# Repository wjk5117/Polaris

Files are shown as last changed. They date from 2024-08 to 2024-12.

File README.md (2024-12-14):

# About
This directory contains all code implementation and hardware designs for Polaris.

# Overview
We present Polaris, the first vision-free fiducial marking system, based on a novel, full-stack magnetic sensing design. 
Polaris can achieve reliable and accurate pose estimation and contextual perception, even in NLOS scenarios. 
Watch our demo video here: [Polaris Demo](https://www.youtube.com/watch?v=gdAEeNdMJk0)

Its core design includes: (1) a novel digital modulation scheme, Magnetic Orientation-shift Keying (MOSK) that can encode key information like waypoints and coordinates with passive magnets; (2) a robust and lightweight magnetic sensing framework to decode and localize the magnetic tags. 
Our design also equips Polaris with three key features: sufficient encoding capacity, robust detection accuracy, and low energy consumption. 
We have built an end-to-end system of Polaris and tested it extensively in real-world scenarios. The testing results have shown Polaris to achieve an accuracy of up to 0.58 mm and 1&deg; in posture estimation with a power consumption of only 25.08 mW.

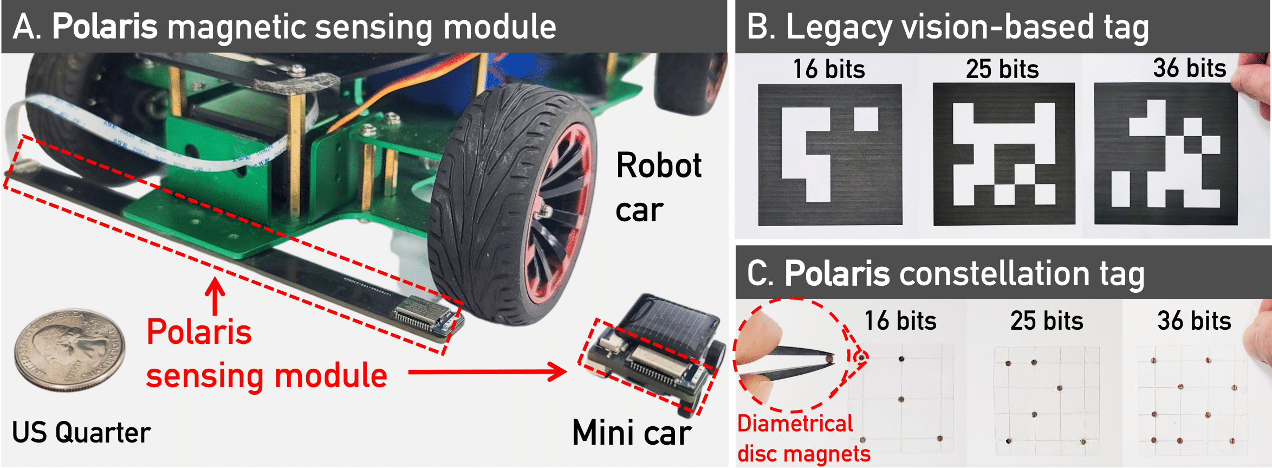
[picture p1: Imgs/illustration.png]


# Setup
To use Polaris, the following steps are required:
* [Building the hardware](#building-the-hardware)
* [Programing the sensor array](#programing-the-sensor-array)
* [Tag fabrication](#tag-fabrication)
* [Running the sensing pipeline](#running-the-sensing-pipeline)

## Building the hardware
We provide the hardware requirements and manufacturing details of Polaris' sensing array in `/PCBs`, please see the related [README](./PCBs/README.md) file.

## Programing the sensor array
We use the Arduino IDE to program the sensor array according to the hardware specifications.
### Arduino IDE setup
1. Download and install the [Arduino IDE](https://www.arduino.cc/en/software). For our prototype, we are using Version 1.8.19.
2. Configure the Arduino IDE for the nRF52 Development Board by following the [official instruction](https://learn.adafruit.com/bluefruit-nrf52-feather-learning-guide/arduino-bsp-setup).
After setup, you can access the board information by clicking on the 'Tools' menu.
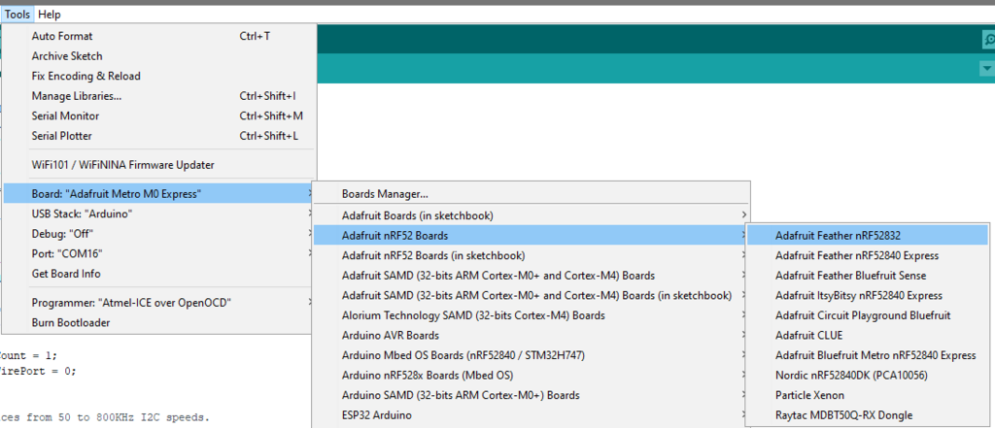
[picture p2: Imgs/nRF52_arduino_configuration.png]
  
3. Install the Adafruit MLX90393 Library for the Arduino IDE:
    - Click 'Sketch' --> 'Include Library' --> 'Manage Libraries...'
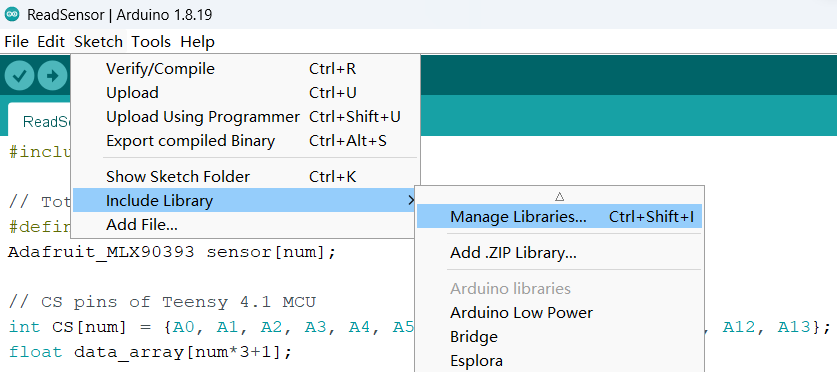
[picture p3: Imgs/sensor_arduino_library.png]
    
    - Search for Adafruit MLX90393, and install the Adafruit MLX90393 library:
    plot

### Programing setup
To program the sensor array using the hardware and Arduino IDE, follow these steps:
1. The microcontroller unit (MCU) in use is the MDBT42Q-512KV2 module, which features a Nordic nRF52832 chip. Since the module is equipped with a blank chip, it needs to be programmed using a J-Link programmer during the initial setup. Please note that this programming step is only required once for a new sensor array.
    - In our prototype, we use a [J-Link EDU Mini](https://www.segger.com/products/debug-probes/j-link/models/j-link-edu-mini/) for programming, one can follow the following hardware setup:
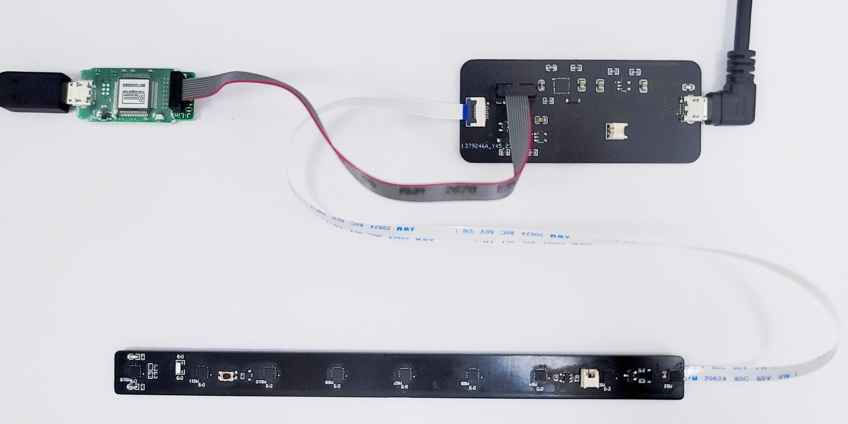
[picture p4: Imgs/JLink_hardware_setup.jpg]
    
    - Open the Arduino IDE --> Click 'Tools' --> Click 'Programmer' --> Choose 'J-Link for Bluefruit nRF52'
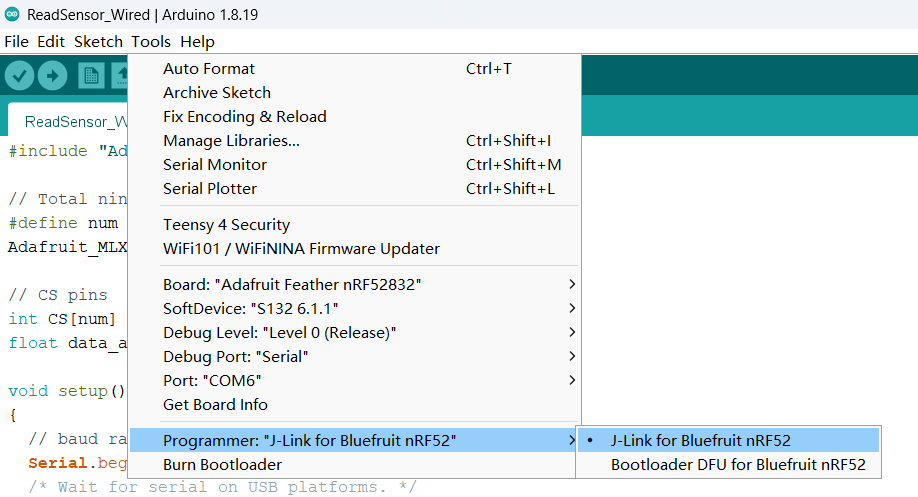
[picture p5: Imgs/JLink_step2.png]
    
    - Click 'Tools' --> Click 'Burn Bootloader'. When you see the following messages, it indicates that the MCU has been programmed successfully.
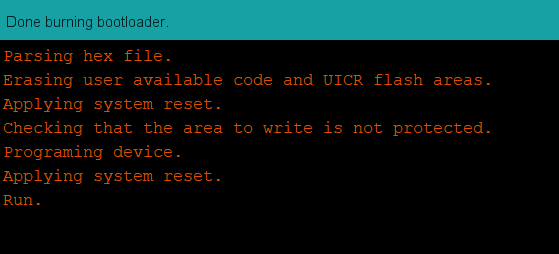
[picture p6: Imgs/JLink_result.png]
    

2. After programming the MCU, you can disconnect the J-Link module and use the Arduino IDE to upload the code that activates the magnetometer readings.
    - Setup the flashing module and the target sensor array and connect to your PC.Make sure the 'Board,' 'Port,' and 'Programmer' settings in the Arduino IDE's 'Tools' menu are properly configured
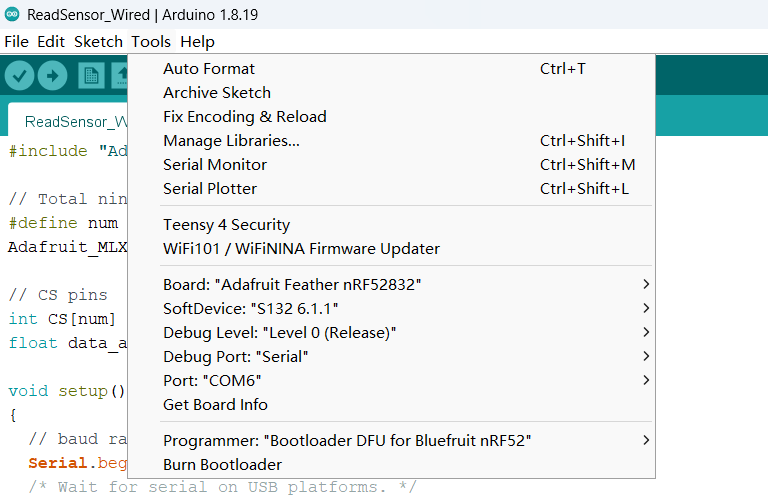
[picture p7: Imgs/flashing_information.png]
    
    - Select the sensing code from the '/Arduino' directory. Both BLE and wired data transmission codes are available for various tasks. Please refer to the relevant file
    - Upload the corresponding Arduino code to the sensor array using the Arduino IDE
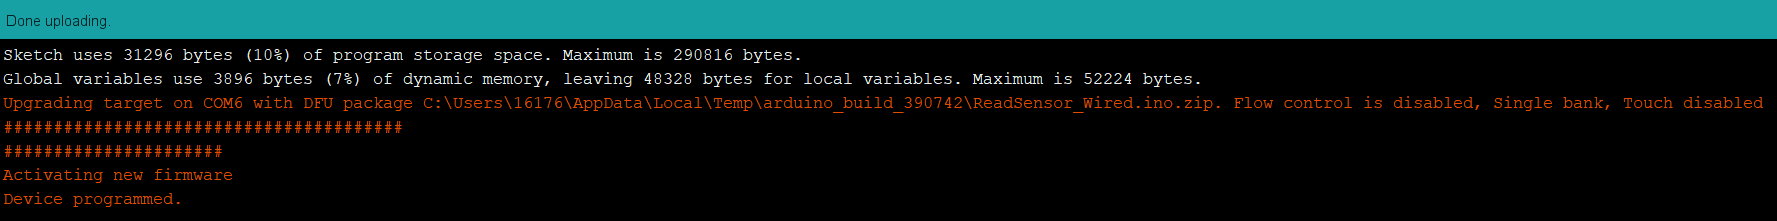
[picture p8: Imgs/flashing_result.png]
    

3. After successfully programming the Arduino code to the sensor array, you can use the Python code in the '/Read_Raw_Sensor' directory to read the raw sensor data.

## Tag fabrication
In our protetype, we use an ultra-thin and durable PVC plane with 
a thickness of 0.2 mm as the substrate and Neodymium (NdFeB) magnets.
To fabricate the tag, we propose a four-step process. 
For more details, please see Sec.7.2 in the paper.
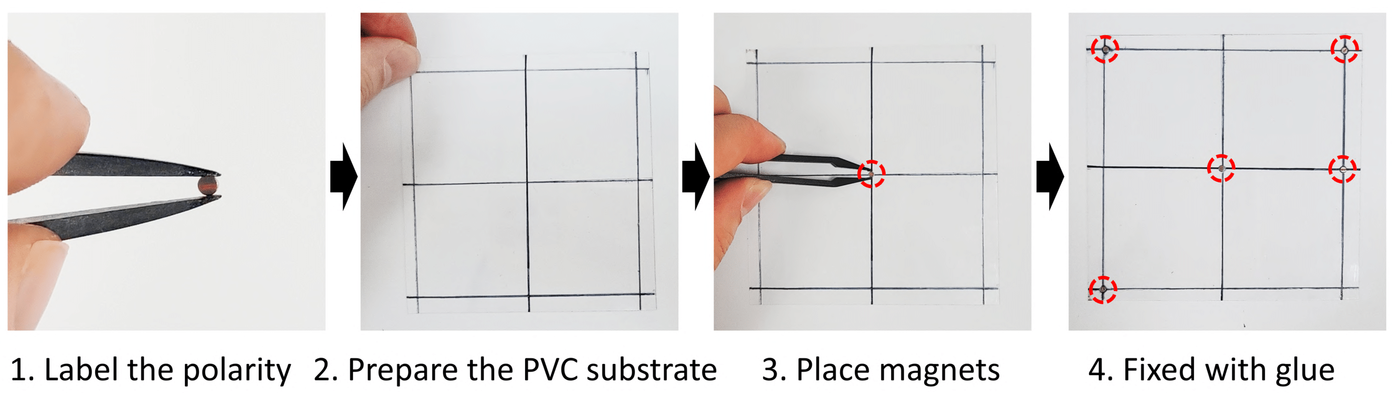
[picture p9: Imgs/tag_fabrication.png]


## Running the sensing pipeline
Once the sensor array is programmed, you can run the Polaris' sensing pipeline. You can find the sensing code in the `/Sensing_Pipeline` directory, please see the related [README](./Sensing_Pipeline/README.md) file.

# Getting started with Polaris
To help users quickly get started with our Polaris system, we’ve provided an offline version of the sensing algorithm framework. 
The relevant data and source code can be found in the the `/Evaluation` directory. 
For more information, please refer to the related [README](./Evaluation/README.md) file.

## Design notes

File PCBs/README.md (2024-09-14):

# Hardware Design of Polaris' Sensor Array

## Description
This directory contains the comprehensive PCB design source codes for Polaris' sensor array, including the sensor bar for fiducial detection and a flashing board for programming the MCU (MDBT42Q-512KV2). 
- The `/SensorArray_RobotCar` directory contains the PCB design for the sensor array used in the robot car.

- The `/SensorArray_MiniCar` directory contains the PCB design for the sensor array used in the mini car.

- The `/Flashing_Module` directory contains the flashing board used to program the MCU for obtaining magnetometer readings.

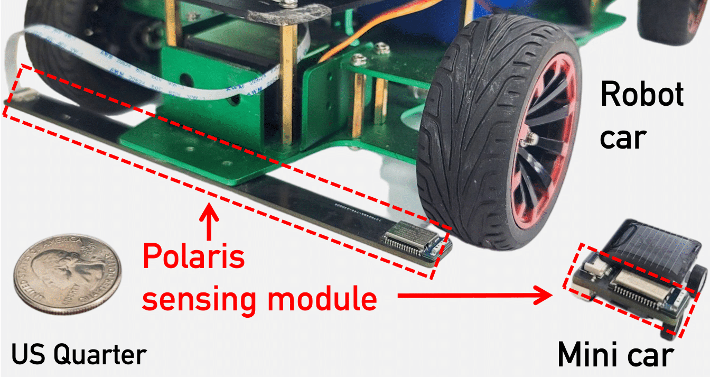
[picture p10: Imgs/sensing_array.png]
plot


## Hardware requirements
The hardware setup requires various components during the design and fabrication process. 
Below is a list of the components used in designing and manufacturing our prototype.

### Sensor array
| Component  | Description | Package | Quantity |
| --- | --- | --- | --- |
|[Raytac MDBT42Q-512KV2](https://www.digikey.com/en/products/detail/raytac/MDBT42Q-512KV2/13677592) | Microcontroller Unit | 41-SMD | 1 |
|[Melexis MLX90393](https://www.digikey.com/en/products/detail/melexis-technologies-nv/MLX90393SLW-ABA-011-RE/5031684) | Magnetometer |16-QFN | M |
|[HCI FC31M2-32.768-NTLNNDTL](https://www.lcsc.com/product-detail/Crystals_HCI-FC31M2-32-768-NTLNNDTL_C5120559.html)  | 32.768kHz Surface Mount Crystal | SMD3215-2P | 1 |
| [Diodes Incorporated AP2112K-3.3TRG1](https://www.lcsc.com/product-detail/Voltage-Regulators-Linear-Low-Drop-Out-LDO-Regulators_Diodes-Incorporated-AP2112K-3-3TRG1_C51118.html)  | Voltage Regulator | SOT-25-5 | 1 |
|[C&K KMR221GLFS](https://www.lcsc.com/product-detail/Tactile-Switches_C-K-KMR221GLFS_C72443.html) | Tactile Switch | SMD | 1 |
| [Vishay Intertech SI2301CDS-T1-GE3](https://www.lcsc.com/product-detail/MOSFETs_Vishay-Intertech-SI2301CDS-T1-GE3_C10487.html) |  P-Channel MOSFET | SOT-23 | 1 |
| [Taiwan Semiconductor 1N4148WS RRG](https://www.lcsc.com/product-detail/Switching-Diodes_Taiwan-Semiconductor-1N4148WS-RRG_C485027.html) | Switching Diodes | SOD-323F | 1 |
| [LRC LMBR120FT1G](https://www.lcsc.com/product-detail/Schottky-Diodes_LRC-LMBR120FT1G_C81143.html) | Schottky Diodes | SOD-123FL | 1 |
| [Resistor](https://www.digikey.com/en/products/filter/chip-resistor-surface-mount/52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) | Chip Resistors | 0402 | 1kΩ (2), 10kΩ (1), 100kΩ (2) |
| [Capacitor](https://www.digikey.com/en/products/filter/ceramic-capacitors/60?s=N4IgTCBcDaIMYEMAOC4EsAuB7ATgAgAYAWAiAXQF8g) | Ceramic Capacitors | 0402| 10uF (3), 1uF (1), 12pF (2), 0.1uF (M) |
| [Inductor](https://www.digikey.com/en/products/filter/fixed-inductors/71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) | Inductors | 0402| 10uH (1), 15nH (1) |
| [Vishay Intertech TLMS1000-GS08](https://www.lcsc.com/product-detail/LED-Indication-Discrete_Vishay-Intertech-TLMS1000-GS08_C241893.html) | LED Indication, Red | 0603 | 1 |
| [Foshan NationStar Optoelectronics NCD0603B1](https://www.lcsc.com/product-detail/LED-Indication-Discrete_Foshan-NationStar-Optoelectronics-NCD0603B1_C84266.html)| LED Indication, Blue  | 0603 | 1 |
| [JUSHUO AFC01-S08FCA-00](https://www.lcsc.com/product-detail/FFC-FPC-Flat-Flexible-Connector-Assemblies_JUSHUO-AFC01-S08FCA-00_C262657.html) |FPC/FFC Connector | SMD, P=0.5mm | 1 |
| [HDGC HDGC1251WR-2P](https://www.lcsc.com/product-detail/Wire-To-Board-Connector_HDGC-HDGC1251WR-2P_C5175203.html) | Wire To Board Connector | Plugin, P=1.25mm | 1 |

### Flashing board
| Component  | Description | Package | Quantity |
| --- | --- | --- | --- |
| [Diodes Incorporated AP2112K-3.3TRG1](https://www.lcsc.com/product-detail/Voltage-Regulators-Linear-Low-Drop-Out-LDO-Regulators_Diodes-Incorporated-AP2112K-3-3TRG1_C51118.html)  | Voltage Regulator | SOT-25-5 | 1 |
| [Vishay Intertech SI2301CDS-T1-GE3](https://www.lcsc.com/product-detail/MOSFETs_Vishay-Intertech-SI2301CDS-T1-GE3_C10487.html) |  P-Channel MOSFET | SOT-23 | 1 |
| [LRC LMBR120FT1G](https://www.lcsc.com/product-detail/Schottky-Diodes_LRC-LMBR120FT1G_C81143.html) | Schottky Diodes | SOD-123FL | 1 |
| [Microchip Tech MCP73831T-2ATI/OT](https://www.lcsc.com/product-detail/Battery-Management_Microchip-Tech-MCP73831T-2ATI-OT_C14879.html) | Battery Management | SOT-23-5 | 1 |
| [SKYWORKS/SILICON LABS CP2104-F03-GM](https://www.lcsc.com/product-detail/USB-Converters_SKYWORKS-SILICON-LABS-CP2104-F03-GM_C430013.html) | USB Converter | QFN-24-EP(4x4)| 1 |
| [TFM-105-12-S-D-A](https://www.digikey.com/en/products/detail/samtec-inc/TFM-105-12-S-D-A/6678838) | Connector Header | SMD 10POS 1.27MM | 1 |
| [Resistor](https://www.digikey.cn/en/products/filter/chip-resistor-surface-mount/52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) | Chip Resistors | 0603 | 1kΩ (3), 100kΩ (3) |
| [Capacitor 0.1uF](https://www.digikey.cn/en/products/filter/ceramic-capacitors/60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) | Ceramic Capacitors | 0603 |  2 |
| [Capacitor 10uF](https://www.digikey.cn/en/products/filter/ceramic-capacitors/60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) | Ceramic Capacitors | 0805 | 5 |
| [PARALIGHT L-C191KRCT](https://www.lcsc.com/product-detail/span-style-background-color-ff0-LED-span-span-style-background-color-ff0-Indication-span-Discrete_PARALIGHT-L-C191KRCT_C2917807.h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) | LED Indication, Orange | 0603 | 1 |
| [SHOU HAN MicroXNJ](https://www.lcsc.com/product-detail/USB-Connectors_SHOU-HAN-MicroXNJ_C404969.html) | Micro-B USB Connectors | SMD | 1 |
| [JUSHUO AFC01-S08FCA-00](https://www.lcsc.com/product-detail/FFC-FPC-Flat-Flexible-Connector-Assemblies_JUSHUO-AFC01-S08FCA-00_C262657.html) |FPC/FFC Connector | SMD, P=0.5mm | 1 |
| [HDGC HDGC1251WR-2P](https://www.lcsc.com/product-detail/Wire-To-Board-Connector_HDGC-HDGC1251WR-2P_C5175203.html) | Wire To Board Connector | Plugin, P=1.25mm | 1 |

## PCB design tool and library
We utilize [EasyEDA](https://easyeda.com/) to design PCB boards.
The component library of capacitive and resistance relies on the standard library.
The footprints for these components can be found in the [EasyEDA 3D model library](https://docs.easyeda.com/en/PCB/3D-Model-Manager/index.html).
The footprint of the MLX90393 magnetometer we used, can see [here](https://www.snapeda.com/parts/MLX90393SLW-ABA-011-RE/Melexis%20Technologies/view-part/551380/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).

After the PCB is manufactured, we also provide an interactive HTML BOM file to facilitate the quick installation of components. 
Please refer to the `BOM.html` file.

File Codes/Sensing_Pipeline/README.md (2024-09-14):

# Sensing Pipeline

## Description
- The `C_Implementation` folder contains a real-time sensing algorithm for detecting Polaris tags implemented in C. 
This code is optimized for low-power devices such as ESP32 chips due to its speed and resource efficiency.

- The `Python_Implementation` folder contains the detection algorithm implemented in Python, which can accelerate algorithm implementation and enhances cross-platform compatibility. It includes:
    - `sensing_real_time.py`: 
    the real-time sensing algorithm for detecting a Polaris tag.
    - `/Utils` folder: 
    contains required utility functions for the sensing pipeline. Specifically, to accelerate the execution of the Python code, we implemented the DDTW algorithm and localization algorithms in C, and embedded them into the Python code as  `.so` (shared object) extension files.
        - `ddtw.c`: C implementation of DDTW algorithm for the polarity orientation.
        - `localize.c`: C implementation of the localization algorithm.
        - `ddtw.so` and `localize.so`: precompiled shared object extension files. 
        To build the `.so` files yourself, use the following command:
            ```
            gcc -shared -o ddtw.so -fPIC ddtw.c -lm 
            ```
    - `template_36_5_80.txt`: 
    this template is generated by synthesizing magnetometer data during the offline stage using Magpylib. 
    It is used to determine the relative orientation of the sensor array with respect to the magnet by DDTW matching process. 
    For more details, please refer to Sec. 6.2.2 of the paper.
    - `requirements.txt`: lists the required Python libraries for the sensing pipeline. 
    You can install each library using the command pip install [library_name]

- The `Simulate_Engine` contains the Python code for generating synthetic magnetic field data templates (e.g., `template_36_5_80.txt`), based on Magpylib. 
The generated templates are used for the magnet polarity orientation matching algorithm. 
For details, please refer to Sec. 6.2.2.

## Note
This directory contains the sensing pipeline for real-time detection, which requires hardwares, e.g., the sensor array and a robot car.
For a quick start with our Polaris system, we’ve provided an offline version of the sensing algorithm framework. 
For more information, please refer to the related [README](../../Evaluation/README.md) file.

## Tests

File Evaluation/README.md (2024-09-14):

# Evaluation-related

## Description
This folder contains all the raw data and code files of the experiments for the artifact submission.

- The `/Data` folder includes all the raw magnetic field readings of three key experiments, saved in CSV format. Each experiment consists of ten sets of data.

- The `/Code` folder contains:
    
    - `sensing_offline.py`: 
    the offline version of the sensing algorithm, which provides quick detection results.
    - `/Utils` folder: 
    contains required utility functions for the sensing pipeline.
    - `template_36_5_80.txt`: 
    this template is generated by synthesizing magnetometer data during the offline stage using Magpylib. 
    It is used to determine the relative orientation of the sensor array with respect to the magnet by DDTW matching process. 
    For more details, please refer to Sec. 6.2.2 of the paper.

- The `/Results` folder contains the processed results for all data, including the estimated heading angle, localization accuracy, tag encoding information, etc.

## How to run
Since the real-time operation of Polaris requires hardware (such as a sensor array), to allow evaluators to quickly get started with our Polaris system, we have provided an offline version of the sensing algorithm framework, `sensing_offline.py`. 
This code reads offline magnetic field data and replicates the results of real-time detection.

To use this code, follow these four simple steps:
- Download our GitHub repository to your local machine.

- Navigate to the `Evaluation/Codes` folder, set up the Python environment, and install the following required libraries:
    - pandas, numpy, datetime, math, ctypes
- Open the `sensing_offline.py` source file, modify `line 598` (the file path to the offline data to be processed) and `line 599` (the file path to save the results) according to your needs. 
    - By default, the code processes the first set of data from the default tag experiment, located at `../Data/Default_Tag/RawData_1.csv`, and saves the results to `../Results/Default_Tag_Exp.txt`.
    ```
    default_tag_file = "../Data/Default_Tag/RawData_1.csv"
    result_txt = "../Results/Default_Tag_Exp.txt"
    ```

- Run the code, and the terminal will display similar information as follows:
    ```
    Begin detecting at 2024-09-10 22:54:56.756350                                           
    Initialize the threshold
    sensor 4: Pre-done with slope threshold equaling to 0.51
    sensor 9: Pre-done with slope threshold equaling to 0.65
    sensor 1: Pre-done with slope threshold equaling to 0.41
    sensor 5: Pre-done with slope threshold equaling to 0.43
    sensor 6: Pre-done with slope threshold equaling to 0.58
    sensor 7: Pre-done with slope threshold equaling to 0.53
    sensor 3: Pre-done with slope threshold equaling to 0.49
    sensor 2: Pre-done with slope threshold equaling to 0.83
    sensor 8: Pre-done with slope threshold equaling to 0.47
    Begin detecting process
    Estimated heading angle: -1.2241516388127511 deg
    The localization error is: 1.4210664527053516 mm
    The decoded bits are: ['111', '111', '111', '111', '111', '111']
    The corresponding tag id is: 262143
    End detection
    ```

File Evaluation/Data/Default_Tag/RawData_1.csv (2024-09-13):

 | Time Stamp | Sensor 1 | Sensor 2 | Sensor 3 | Sensor 4 | Sensor 5 | Sensor 6 | Sensor 7 | Sensor 8 | Sensor 9
0 | 0.0 | (55.95, 9.0, 22.99) | (31.05, -13.5, 63.162) | (23.7, 7.95, 58.564) | (16.8, -5.25, 28.072) | (10.35, -15.3, 42.834) | (2.4, -5.4, 25.41) | (-4.2, -8.85, 43.318) | (9.15, -11.55, 28.556) | (0.6, -19.8, 34.122)
1 | 0.01 | (58.2, 10.65, 24.2) | (34.95, -14.55, 66.55) | (24.0, 6.3, 60.258) | (17.85, -5.25, 28.798) | (9.3, -16.35, 39.688) | (1.2, -6.3, 27.104) | (-2.7, -7.5, 40.898) | (8.25, -9.6, 27.346) | (1.65, -20.25, 32.186)
2 | 0.02 | (55.35, 9.3, 23.716) | (33.75, -14.1, 66.308) | (22.8, 4.95, 59.774) | (16.95, -4.5, 30.25) | (10.65, -14.7, 46.222) | (0.75, -6.0, 25.168) | (-2.1, -6.75, 40.172) | (8.1, -10.8, 29.766) | (1.65, -20.4, 33.638)
3 | 0.03 | (56.25, 9.15, 22.506) | (34.35, -14.1, 66.066) | (23.4, 6.45, 60.258) | (17.1, -6.0, 28.314) | (9.15, -14.55, 41.14) | (2.85, -6.9, 27.104) | (-2.7, -7.35, 41.624) | (7.95, -10.2, 26.378) | (1.2, -21.0, 34.364)
4 | 0.04 | (57.15, 10.05, 23.958) | (37.35, -17.7, 68.97) | (22.8, 6.75, 57.112) | (16.8, -4.65, 28.072) | (9.9, -16.35, 43.56) | (0.0, -6.75, 25.894) | (-1.35, -7.8, 42.834) | (7.35, -10.65, 28.072) | (3.0, -19.5, 35.816)
5 | 0.05 | (56.7, 8.4, 24.2) | (36.9, -12.6, 62.92) | (24.6, 7.2, 60.742) | (16.35, -6.15, 30.734) | (9.6, -16.05, 42.35) | (0.45, -5.25, 26.62) | (-2.1, -9.15, 45.012) | (10.05, -10.05, 29.282) | (2.1, -19.95, 32.912)
6 | 0.060000000000000005 | (55.5, 7.95, 22.99) | (36.0, -12.75, 68.244) | (22.8, 7.05, 59.532) | (18.0, -4.95, 27.104) | (9.3, -14.4, 41.624) | (0.6, -7.05, 26.62) | (-1.95, -9.15, 40.656) | (6.45, -10.8, 28.556) | (2.4, -20.25, 33.154)
7 | 0.07 | (56.55, 9.9, 23.716) | (37.2, -11.1, 65.098) | (24.6, 4.8, 60.984) | (17.25, -6.45, 27.346) | (10.5, -16.05, 43.076) | (2.4, -4.65, 24.926) | (-3.75, -8.1, 42.592) | (8.1, -10.35, 30.008) | (2.85, -19.35, 33.638)
8 | 0.08 | (54.6, 9.0, 24.926) | (34.8, -14.7, 66.308) | (24.15, 6.45, 56.628) | (16.5, -4.5, 27.83) | (10.2, -15.15, 43.318) | (0.15, -5.1, 27.83) | (-2.7, -8.7, 43.802) | (8.4, -10.5, 28.798) | (1.95, -20.25, 32.428)
9 | 0.09 | (56.85, 9.0, 24.442) | (35.25, -11.85, 66.308) | (22.65, 7.8, 59.774) | (17.25, -5.55, 27.588) | (10.35, -15.75, 42.592) | (-0.3, -5.85, 27.104) | (-2.7, -8.7, 42.592) | (7.5, -9.6, 29.766) | (1.5, -21.45, 34.848)
10 | 0.09999999999999999 | (57.75, 8.1, 22.99) | (37.65, -14.7, 65.34) | (24.3, 4.65, 60.016) | (16.8, -6.15, 30.734) | (9.9, -17.55, 43.802) | (1.2, -7.5, 27.346) | (-3.45, -9.0, 41.624) | (9.0, -12.0, 31.218) | (2.7, -20.4, 33.88)
11 | 0.10999999999999999 | (57.15, 9.3, 23.474) | (32.4, -11.25, 64.372) | (22.65, 8.1, 58.322) | (17.55, -5.7, 29.282) | (10.95, -17.55, 41.866) | (2.7, -6.0, 25.41) | (-1.5, -9.3, 42.108) | (8.25, -10.05, 28.556) | (3.0, -19.8, 35.816)
12 | 0.11999999999999998 | (56.1, 8.7, 22.99) | (33.6, -12.9, 65.824) | (22.05, 4.65, 60.742) | (16.8, -5.25, 27.588) | (11.1, -14.4, 41.382) | (0.3, -8.1, 27.83) | (-2.7, -6.75, 41.866) | (8.85, -9.9, 29.04) | (2.55, -19.8, 35.574)
13 | 0.12999999999999998 | (55.95, 10.05, 22.99) | (35.55, -15.3, 61.71) | (22.5, 7.35, 57.354) | (17.1, -5.25, 30.734) | (10.05, -16.8, 42.592) | (2.55, -4.65, 25.652) | (-2.1, -9.0, 41.624) | (9.0, -10.2, 27.83) | (2.55, -22.05, 32.67)
14 | 0.13999999999999999 | (56.85, 9.6, 22.022) | (34.95, -13.65, 66.308) | (23.1, 7.2, 59.048) | (18.0, -4.2, 29.282) | (10.35, -15.9, 41.382) | (2.7, -5.85, 24.684) | (-4.2, -8.55, 41.624) | (7.8, -10.2, 30.25) | (2.7, -19.8, 33.396)
15 | 0.15 | (55.95, 8.25, 22.99) | (36.15, -12.3, 65.098) | (22.35, 4.95, 57.596) | (17.1, -6.9, 28.314) | (8.55, -16.8, 40.898) | (0.75, -7.8, 26.62) | (-3.6, -9.45, 41.14) | (9.75, -11.4, 28.556) | (1.5, -20.85, 33.638)
16 | 0.16 | (55.8, 9.45, 23.232) | (32.4, -12.45, 64.856) | (22.5, 4.05, 58.806) | (17.25, -5.7, 29.282) | (10.05, -15.3, 41.14) | (1.95, -7.05, 25.652) | (-3.45, -6.45, 39.93) | (9.3, -11.55, 28.798) | (3.0, -20.55, 35.816)
17 | 0.17 | (57.6, 9.6, 23.232) | (36.15, -13.2, 66.308) | (24.3, 5.7, 58.08) | (16.5, -5.1, 29.282) | (10.95, -17.25, 40.898) | (2.55, -6.75, 26.136) | (-2.4, -9.75, 42.108) | (9.75, -11.55, 27.588) | (3.0, -19.2, 34.122)
18 | 0.18000000000000002 | (55.8, 9.45, 23.716) | (35.55, -14.7, 68.97) | (21.45, 4.2, 60.984) | (16.5, -5.25, 28.072) | (9.6, -14.55, 41.382) | (2.85, -7.35, 25.652) | (-1.2, -8.85, 41.624) | (8.1, -9.6, 29.766) | (1.8, -18.9, 33.396)
19 | 0.19000000000000003 | (55.65, 9.75, 23.716) | (35.85, -13.65, 69.212) | (22.35, 4.8, 58.322) | (17.7, -4.5, 29.524) | (10.35, -16.5, 42.108) | (2.55, -6.3, 25.652) | (-2.7, -10.05, 41.624) | (7.5, -9.9, 30.008) | (1.95, -21.3, 35.816)
20 | 0.20000000000000004 | (56.1, 8.55, 23.232) | (33.9, -13.35, 64.13) | (23.55, 5.7, 57.596) | (16.8, -4.5, 29.524) | (9.15, -16.35, 42.834) | (0.45, -7.5, 26.862) | (-2.7, -8.55, 40.656) | (8.55, -11.1, 27.588) | (1.35, -21.15, 33.154)
21 | 0.21000000000000005 | (55.5, 8.4, 23.232) | (35.85, -12.6, 65.824) | (22.5, 5.4, 60.258) | (15.9, -5.7, 29.282) | (8.85, -17.25, 41.624) | (0.6, -6.45, 27.588) | (-2.1, -9.3, 41.866) | (8.7, -10.2, 28.072) | (2.1, -21.9, 34.122)
22 | 0.22000000000000006 | (55.8, 7.8, 23.958) | (38.1, -16.65, 68.002) | (25.05, 5.25, 54.208) | (16.65, -4.2, 30.25) | (9.0, -16.2, 41.14) | (0.3, -7.95, 26.62) | (-1.8, -7.95, 43.076) | (8.85, -11.4, 29.04) | (1.65, -20.7, 36.058)
23 | 0.23000000000000007 | (56.4, 10.05, 23.716) | (34.5, -13.95, 65.824) | (25.65, 5.85, 57.112) | (17.55, -7.5, 30.734) | (9.6, -17.7, 42.108) | (1.5, -6.3, 24.442) | (-2.85, -8.85, 40.414) | (8.25, -9.45, 27.346) | (3.15, -21.3, 32.428)
24 | 0.24000000000000007 | (58.05, 10.35, 22.506) | (34.05, -11.1, 68.486) | (21.6, 3.3, 57.596) | (15.75, -6.0, 28.072) | (11.7, -16.65, 41.14) | (1.8, -7.65, 25.652) | (-0.75, -7.95, 42.108) | (8.1, -9.6, 31.218) | (1.8, -21.45, 33.88)
25 | 0.25000000000000006 | (56.1, 8.7, 23.474) | (37.35, -15.6, 68.244) | (22.95, 4.5, 59.532) | (17.55, -4.95, 30.25) | (10.65, -16.65, 42.35) | (1.5, -5.25, 27.588) | (-1.65, -8.25, 40.898) | (8.25, -10.05, 29.766) | (2.25, -20.4, 34.848)
26 | 0.26000000000000006 | (57.6, 7.5, 24.442) | (35.4, -15.9, 66.308) | (22.95, 5.25, 57.596) | (17.25, -5.85, 27.83) | (11.25, -16.65, 42.108) | (2.1, -6.0, 26.62) | (-4.2, -7.5, 43.802) | (7.8, -11.55, 30.492) | (2.4, -21.15, 30.008)
27 | 0.2700000000000001 | (55.5, 9.3, 24.442) | (35.55, -14.55, 66.066) | (23.1, 5.7, 55.418) | (17.1, -5.25, 30.008) | (8.85, -17.4, 41.14) | (0.9, -7.65, 25.168) | (-4.5, -9.6, 41.624) | (10.35, -10.8, 25.41) | (2.25, -19.2, 34.364)
28 | 0.2800000000000001 | (56.25, 7.65, 23.474) | (37.8, -16.05, 63.888) | (24.3, 4.05, 57.596) | (16.65, -3.9, 28.072) | (9.15, -16.8, 44.77) | (1.95, -5.7, 26.862) | (-1.8, -8.25, 41.624) | (8.55, -12.0, 27.104) | (1.35, -22.2, 34.606)
29 | 0.2900000000000001 | (57.6, 9.15, 24.684) | (34.95, -12.45, 68.97) | (24.6, 7.8, 56.628) | (16.05, -5.1, 28.556) | (10.2, -17.4, 41.382) | (0.6, -6.75, 24.926) | (-3.45, -7.65, 42.592) | (8.85, -11.25, 30.25) | (2.25, -20.4, 34.848)
30 | 0.3000000000000001 | (56.85, 9.6, 23.716) | (35.4, -12.9, 65.582) | (24.6, 4.05, 57.838) | (17.1, -4.35, 29.282) | (11.25, -16.2, 42.35) | (2.4, -7.5, 29.282) | (-2.85, -9.3, 43.56) | (8.85, -10.35, 28.798) | (1.2, -22.05, 35.816)
31 | 0.3100000000000001 | (57.45, 9.45, 22.99) | (34.8, -14.4, 64.372) | (23.7, 5.55, 59.29) | (17.7, -5.55, 30.008) | (8.7, -16.95, 42.834) | (2.7, -7.35, 29.766) | (-4.35, -10.05, 43.076) | (8.85, -10.2, 27.104) | (3.0, -21.6, 33.638)
32 | 0.3200000000000001 | (56.1, 9.15, 24.442) | (35.55, -12.75, 64.372) | (22.2, 6.75, 56.87) | (18.3, -4.65, 27.104) | (9.3, -16.95, 44.286) | (3.45, -6.45, 26.136) | (-4.05, -8.1, 40.898) | (9.6, -9.45, 28.556) | (1.65, -21.0, 32.67)
33 | 0.3300000000000001 | (57.15, 9.45, 23.474) | (34.8, -14.25, 64.372) | (25.2, 5.85, 55.902) | (17.85, -5.85, 28.072) | (11.55, -15.75, 39.93) | (1.5, -7.05, 24.684) | (-3.0, -9.3, 39.688) | (9.0, -10.5, 29.282) | (3.0, -20.25, 32.912)
34 | 0.34000000000000014 | (55.65, 7.8, 23.474) | (34.2, -13.05, 67.034) | (21.15, 2.55, 60.5) | (14.55, -4.95, 28.314) | (9.15, -17.1, 41.14) | (1.65, -6.75, 26.62) | (-3.0, -8.25, 41.14) | (7.8, -10.35, 27.104) | (2.1, -20.7, 33.396)
35 | 0.35000000000000014 | (56.85, 8.4, 22.748) | (34.35, -13.5, 65.582) | (23.7, 2.85, 56.386) | (16.8, -6.15, 28.314) | (10.05, -15.45, 41.14) | (1.35, -6.15, 25.41) | (-2.85, -8.55, 42.35) | (8.7, -10.65, 28.314) | (3.9, -20.25, 33.88)
36 | 0.36000000000000015 | (56.25, 7.8, 23.474) | (35.25, -15.3, 66.308) | (22.35, 4.05, 56.144) | (16.65, -5.85, 30.976) | (10.2, -15.9, 42.35) | (2.25, -7.8, 26.62) | (-2.55, -8.1, 39.688) | (8.1, -9.9, 26.862) | (2.85, -21.15, 31.218)
37 | 0.37000000000000016 | (56.55, 8.85, 23.232) | (37.2, -16.05, 68.486) | (23.7, 4.65, 59.048) | (17.55, -6.15, 27.83) | (10.5, -15.75, 39.93) | (2.7, -8.4, 27.346) | (-3.15, -9.3, 41.624) | (9.6, -9.15, 30.25) | (2.25, -20.7, 33.638)
38 | 0.38000000000000017 | (55.95, 9.6, 22.99) | (35.85, -12.75, 67.276) | (21.15, 7.8, 59.774) | (16.65, -5.85, 28.556) | (11.1, -16.5, 42.592) | (3.6, -6.15, 23.716) | (-3.15, -8.7, 42.35) | (7.95, -10.5, 31.46) | (1.65, -20.25, 34.848)
39 | 0.3900000000000002 | (58.2, 8.55, 22.506) | (33.75, -12.75, 63.162) | (21.9, 4.95, 58.08) | (17.85, -3.45, 28.314) | (10.5, -15.45, 40.898) | (0.9, -5.85, 26.136) | (-3.6, -8.4, 43.076) | (8.55, -9.3, 27.588) | (3.75, -20.1, 34.122)
40 | 0.4000000000000002 | (55.65, 11.1, 22.748) | (38.25, -15.45, 66.308) | (23.85, 5.7, 60.742) | (17.1, -5.55, 28.556) | (9.0, -15.75, 41.382) | (2.4, -7.8, 25.652) | (-3.9, -9.0, 40.656) | (9.0, -10.5, 29.282) | (2.55, -19.8, 33.88)
41 | 0.4100000000000002 | (57.6, 9.0, 22.99) | (35.85, -13.8, 68.486) | (23.7, 6.3, 55.902) | (15.75, -3.3, 25.894) | (9.45, -15.6, 41.14) | (1.65, -7.05, 29.524) | (-2.1, -9.75, 43.076) | (7.8, -10.65, 26.62) | (1.5, -20.85, 37.994)
42 | 0.4200000000000002 | (57.0, 9.45, 23.474) | (36.9, -14.25, 66.308) | (20.1, 5.4, 54.692) | (17.7, -6.15, 29.282) | (10.2, -15.9, 40.898) | (1.8, -6.9, 25.894) | (-1.65, -8.85, 41.382) | (8.1, -10.65, 29.524) | (2.1, -19.95, 35.816)
43 | 0.4300000000000002 | (55.65, 9.6, 23.474) | (36.3, -15.15, 67.034) | (22.65, 5.4, 57.838) | (15.9, -6.0, 29.282) | (10.05, -16.8, 42.834) | (3.3, -6.75, 27.83) | (-2.85, -7.05, 42.108) | (9.6, -10.95, 30.25) | (3.75, -22.05, 34.848)
44 | 0.4400000000000002 | (57.45, 9.15, 22.99) | (36.6, -14.4, 68.728) | (22.65, 4.5, 57.354) | (16.5, -5.1, 29.282) | (10.5, -15.15, 43.318) | (2.4, -6.0, 28.556) | (-4.5, -10.5, 41.624) | (8.85, -9.6, 28.798) | (1.2, -19.8, 31.218)
45 | 0.45000000000000023 | (56.4, 10.65, 22.99) | (34.35, -12.15, 68.002) | (23.85, 2.85, 57.596) | (17.55, -5.25, 29.282) | (9.45, -16.65, 42.35) | (0.75, -6.0, 28.314) | (-2.7, -8.4, 41.866) | (6.9, -10.95, 30.976) | (1.65, -20.4, 32.428)
46 | 0.46000000000000024 | (56.55, 10.35, 21.78) | (37.5, -14.1, 66.55) | (22.05, 3.6, 54.692) | (16.8, -5.25, 28.556) | (10.5, -15.75, 41.624) | (2.55, -5.7, 28.556) | (-3.45, -7.95, 42.108) | (8.4, -9.75, 30.976) | (1.5, -21.3, 34.606)
47 | 0.47000000000000025 | (55.05, 6.9, 22.264) | (33.3, -13.2, 67.276) | (22.5, 4.2, 58.806) | (15.6, -4.5, 27.346) | (10.05, -15.15, 39.204) | (2.55, -6.6, 23.958) | (-2.4, -8.7, 40.898) | (10.35, -10.8, 28.314) | (2.55, -21.9, 33.88)
48 | 0.48000000000000026 | (59.1, 9.3, 23.474) | (36.9, -14.1, 65.824) | (21.0, 5.85, 57.354) | (18.0, -5.1, 27.346) | (11.1, -15.3, 43.318) | (1.8, -6.45, 26.136) | (-4.35, -8.7, 41.14) | (8.1, -10.2, 29.282) | (4.05, -20.25, 33.88)
49 | 0.49000000000000027 | (56.4, 9.6, 23.474) | (34.35, -16.05, 64.614) | (22.35, 4.2, 55.902) | (17.85, -4.2, 29.766) | (10.8, -16.35, 42.834) | (1.35, -6.3, 24.926) | (-3.6, -9.45, 40.656) | (7.35, -10.35, 29.04) | (2.25, -19.8, 33.88)
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

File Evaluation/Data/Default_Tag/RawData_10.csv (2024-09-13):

 | Time Stamp | Sensor 1 | Sensor 2 | Sensor 3 | Sensor 4 | Sensor 5 | Sensor 6 | Sensor 7 | Sensor 8 | Sensor 9
0 | 0.0 | (54.75, 15.15, 47.19) | (36.45, -14.4, 65.824) | (22.95, 6.0, 55.66) | (16.95, -4.8, 27.346) | (9.15, -16.35, 42.35) | (0.9, -6.45, 27.588) | (-1.35, -8.85, 39.93) | (8.25, -9.75, 28.798) | (2.85, -19.2, 35.574)
1 | 0.01 | (58.05, 9.3, 48.884) | (34.5, -13.65, 64.13) | (23.85, 3.15, 60.742) | (18.0, -4.2, 28.072) | (9.45, -15.6, 41.866) | (2.55, -5.1, 25.894) | (-2.4, -9.3, 41.14) | (8.4, -6.9, 28.798) | (2.25, -18.9, 36.3)
2 | 0.02 | (58.5, 9.9, 47.674) | (33.9, -12.3, 61.71) | (22.2, 3.75, 55.902) | (16.5, -6.75, 28.556) | (9.75, -15.6, 41.866) | (1.95, -5.85, 26.862) | (-2.7, -9.45, 41.14) | (8.55, -7.8, 29.766) | (1.2, -17.55, 35.332)
3 | 0.03 | (57.6, 8.7, 50.82) | (34.8, -13.2, 64.614) | (22.65, 1.65, 56.87) | (15.9, -5.85, 29.282) | (10.95, -16.2, 41.14) | (4.35, -8.7, 26.862) | (-2.1, -9.0, 39.688) | (8.25, -7.35, 28.798) | (4.05, -18.6, 35.816)
4 | 0.04 | (56.4, 10.65, 45.738) | (35.1, -12.15, 64.856) | (22.35, 4.35, 54.934) | (17.1, -6.6, 30.734) | (11.4, -16.95, 43.802) | (3.75, -8.85, 26.62) | (-2.85, -9.6, 41.866) | (10.05, -8.55, 28.798) | (1.35, -19.5, 36.3)
5 | 0.05 | (55.65, 7.8, 48.642) | (37.8, -13.95, 63.404) | (22.35, 4.2, 57.354) | (18.15, -6.3, 27.104) | (10.8, -16.35, 42.35) | (5.85, -9.6, 25.894) | (-0.6, -7.35, 42.592) | (8.7, -8.1, 28.798) | (2.55, -18.0, 33.396)
6 | 0.060000000000000005 | (56.7, 9.15, 46.222) | (34.2, -12.75, 65.582) | (23.1, 5.1, 55.418) | (18.45, -5.85, 27.104) | (9.75, -15.9, 44.77) | (4.8, -7.95, 27.588) | (-2.4, -7.2, 40.898) | (9.6, -8.7, 28.556) | (1.95, -18.3, 34.364)
7 | 0.07 | (56.1, 8.55, 44.286) | (35.1, -14.25, 63.646) | (22.05, 4.8, 56.386) | (16.2, -4.5, 27.346) | (10.8, -15.15, 43.318) | (4.5, -5.4, 25.168) | (-3.15, -9.15, 41.14) | (7.2, -7.8, 28.798) | (2.1, -18.3, 34.364)
8 | 0.08 | (56.25, 9.75, 44.528) | (34.95, -13.8, 65.098) | (22.95, 1.35, 58.806) | (18.0, -5.55, 27.83) | (12.45, -13.8, 42.108) | (3.15, -4.35, 26.378) | (-1.65, -7.8, 41.382) | (9.9, -8.85, 30.492) | (4.95, -18.15, 32.428)
9 | 0.09 | (58.95, 8.55, 42.35) | (35.85, -13.95, 64.13) | (23.25, 6.0, 56.144) | (16.8, -3.45, 30.008) | (11.55, -14.4, 42.108) | (1.35, -4.5, 27.588) | (-3.45, -6.45, 40.898) | (7.8, -8.25, 28.798) | (1.8, -17.85, 32.67)
10 | 0.09999999999999999 | (60.45, 10.2, 50.82) | (34.65, -12.0, 62.92) | (21.3, 5.55, 53.966) | (16.35, -5.7, 29.524) | (10.8, -15.15, 44.044) | (1.65, -3.75, 27.346) | (-2.55, -6.3, 41.624) | (9.45, -8.1, 29.524) | (0.75, -19.8, 36.3)
11 | 0.10999999999999999 | (58.95, 11.55, 50.82) | (35.25, -14.55, 66.55) | (24.15, 3.6, 57.354) | (16.95, -5.1, 29.524) | (9.3, -14.55, 41.14) | (2.25, -4.8, 29.04) | (-2.1, -7.05, 42.592) | (10.5, -8.85, 29.524) | (2.55, -19.65, 33.638)
12 | 0.11999999999999998 | (59.1, 8.55, 45.254) | (34.35, -11.55, 64.372) | (23.55, 4.2, 55.418) | (17.7, -6.0, 27.83) | (9.3, -15.45, 43.318) | (2.25, -6.0, 26.862) | (-1.35, -7.65, 42.108) | (7.95, -9.0, 31.46) | (2.25, -17.85, 34.848)
13 | 0.12999999999999998 | (56.25, 10.2, 48.158) | (34.35, -14.4, 64.614) | (22.95, 3.9, 57.838) | (16.95, -6.3, 26.62) | (9.45, -16.35, 43.076) | (3.15, -7.05, 28.798) | (-2.55, -7.05, 39.688) | (7.35, -9.6, 30.008) | (2.25, -18.9, 34.606)
14 | 0.13999999999999999 | (57.3, 7.5, 46.706) | (34.05, -14.7, 64.13) | (21.75, 4.65, 52.272) | (15.9, -4.95, 28.314) | (10.95, -16.35, 44.77) | (1.95, -5.1, 26.136) | (-2.85, -7.35, 38.478) | (6.75, -7.8, 29.524) | (2.25, -19.05, 37.026)
15 | 0.15 | (57.75, 12.0, 44.77) | (35.1, -14.25, 63.162) | (21.75, 5.4, 57.112) | (17.7, -3.45, 27.104) | (9.3, -14.4, 41.14) | (1.95, -4.8, 27.346) | (-2.25, -6.45, 43.802) | (8.55, -8.25, 30.976) | (2.4, -17.55, 34.364)
16 | 0.16 | (55.8, 10.65, 45.496) | (34.65, -14.7, 66.066) | (22.35, 3.9, 55.418) | (16.35, -4.95, 26.378) | (10.5, -12.75, 42.834) | (0.3, -6.0, 29.282) | (-2.4, -8.25, 43.076) | (7.65, -8.7, 29.524) | (1.65, -18.9, 35.816)
17 | 0.17 | (57.6, 12.9, 51.546) | (34.8, -10.8, 65.824) | (21.75, 6.75, 57.112) | (16.05, -5.1, 29.524) | (11.1, -15.3, 42.834) | (4.05, -4.5, 25.894) | (-1.8, -6.9, 42.834) | (8.55, -8.1, 30.25) | (2.4, -18.45, 34.364)
18 | 0.18000000000000002 | (56.25, 10.2, 45.012) | (36.3, -14.85, 63.888) | (21.0, 5.1, 54.692) | (17.85, -5.4, 28.072) | (10.8, -14.25, 41.14) | (3.75, -6.75, 28.314) | (-2.7, -7.05, 43.318) | (7.95, -7.05, 31.702) | (4.05, -18.3, 34.606)
19 | 0.19000000000000003 | (53.7, 9.3, 45.98) | (36.0, -12.75, 64.614) | (23.55, 2.55, 54.208) | (16.35, -5.1, 24.684) | (10.35, -16.05, 41.624) | (1.65, -4.65, 27.588) | (-1.35, -7.65, 40.414) | (9.9, -9.0, 30.008) | (3.6, -18.15, 34.606)
20 | 0.20000000000000004 | (55.65, 10.35, 41.866) | (36.15, -15.75, 64.372) | (21.9, 5.4, 55.66) | (15.9, -6.3, 25.652) | (9.9, -15.15, 41.382) | (1.8, -7.2, 27.588) | (-2.85, -8.25, 41.866) | (8.25, -7.2, 32.428) | (3.6, -19.8, 34.364)
21 | 0.21000000000000005 | (58.35, 10.95, 48.158) | (34.95, -14.7, 67.034) | (24.3, 2.7, 58.806) | (17.55, -5.7, 28.314) | (10.2, -16.35, 41.624) | (3.9, -5.85, 27.346) | (-3.45, -9.45, 41.382) | (10.35, -9.6, 29.766) | (2.4, -18.45, 35.816)
22 | 0.22000000000000006 | (59.25, 6.45, 50.82) | (36.75, -13.8, 66.792) | (24.6, 3.0, 54.934) | (16.2, -6.0, 26.136) | (8.7, -16.65, 41.624) | (1.95, -5.55, 26.862) | (-1.8, -8.25, 43.076) | (9.0, -8.55, 31.702) | (2.4, -19.5, 33.638)
23 | 0.23000000000000007 | (56.7, 8.25, 47.432) | (32.7, -12.75, 64.614) | (23.55, 2.55, 54.934) | (17.55, -6.15, 27.83) | (10.8, -16.05, 40.172) | (3.3, -6.3, 24.684) | (-2.25, -6.6, 41.14) | (9.0, -8.4, 29.04) | (2.25, -19.65, 35.09)
24 | 0.24000000000000007 | (56.55, 7.8, 46.706) | (36.45, -14.25, 64.13) | (23.1, 4.8, 55.902) | (16.8, -6.9, 26.62) | (9.3, -15.9, 41.866) | (1.05, -5.85, 25.41) | (-1.65, -8.55, 41.382) | (8.7, -7.2, 30.008) | (2.7, -19.8, 33.154)
25 | 0.25000000000000006 | (56.7, 11.25, 52.03) | (35.25, -12.3, 61.226) | (21.75, 3.15, 57.596) | (16.95, -6.9, 25.168) | (10.8, -17.1, 43.56) | (2.1, -5.25, 28.072) | (-1.65, -8.4, 40.656) | (9.9, -7.2, 28.798) | (3.15, -19.2, 34.364)
26 | 0.26000000000000006 | (58.8, 9.45, 47.432) | (36.9, -13.05, 64.372) | (23.55, 2.7, 55.902) | (15.45, -4.95, 27.588) | (10.95, -16.5, 43.56) | (2.4, -6.3, 26.136) | (-2.1, -7.65, 40.172) | (7.95, -8.1, 29.524) | (1.8, -19.65, 31.218)
27 | 0.2700000000000001 | (59.85, 7.8, 47.19) | (34.35, -13.65, 60.5) | (25.05, 6.75, 56.386) | (18.15, -6.0, 29.282) | (12.3, -16.65, 42.108) | (0.45, -5.4, 26.136) | (-2.25, -8.7, 40.898) | (8.55, -6.75, 30.492) | (1.95, -18.3, 33.154)
28 | 0.2800000000000001 | (58.65, 11.25, 45.496) | (36.9, -12.9, 64.13) | (22.05, 6.3, 56.87) | (18.0, -6.15, 26.62) | (11.4, -16.05, 43.802) | (3.15, -5.55, 25.41) | (-1.65, -7.95, 41.14) | (9.0, -7.05, 30.734) | (2.85, -18.6, 34.848)
29 | 0.2900000000000001 | (58.05, 10.2, 47.432) | (34.35, -12.6, 63.888) | (25.2, 3.45, 56.386) | (18.45, -6.45, 26.862) | (11.1, -16.2, 40.172) | (3.15, -6.6, 27.83) | (-2.85, -8.1, 40.898) | (9.3, -7.5, 30.976) | (2.25, -19.05, 34.364)
30 | 0.3000000000000001 | (55.95, 11.25, 41.624) | (36.75, -14.55, 64.13) | (24.9, 1.95, 54.692) | (18.45, -6.0, 28.556) | (11.1, -16.2, 44.528) | (2.85, -6.3, 26.378) | (-3.0, -7.5, 39.204) | (9.15, -8.1, 28.798) | (1.5, -19.05, 34.122)
31 | 0.3100000000000001 | (58.95, 9.75, 47.432) | (37.8, -12.45, 64.614) | (23.25, 3.45, 58.564) | (18.9, -6.75, 26.862) | (10.35, -16.2, 43.318) | (1.95, -5.25, 26.136) | (-1.8, -9.0, 39.93) | (9.6, -7.8, 30.492) | (3.6, -19.8, 32.67)
32 | 0.3200000000000001 | (56.4, 12.3, 47.19) | (34.2, -9.9, 64.13) | (20.85, 1.05, 55.66) | (18.0, -5.1, 29.282) | (11.4, -16.65, 40.656) | (1.95, -6.3, 27.104) | (-0.9, -7.35, 37.994) | (9.15, -8.1, 31.46) | (3.3, -19.5, 33.88)
33 | 0.3300000000000001 | (58.65, 9.45, 46.948) | (35.1, -12.15, 63.162) | (22.65, 4.05, 57.596) | (19.05, -6.0, 26.378) | (11.1, -15.3, 43.076) | (2.4, -6.0, 27.104) | (-4.35, -8.85, 40.656) | (9.15, -7.65, 29.282) | (3.0, -17.85, 34.364)
34 | 0.34000000000000014 | (61.05, 8.1, 48.642) | (33.9, -14.4, 62.92) | (23.1, 2.7, 56.144) | (17.4, -5.85, 27.104) | (11.1, -16.2, 41.382) | (3.45, -8.1, 29.04) | (-2.4, -7.8, 40.898) | (9.0, -7.35, 28.072) | (2.85, -18.75, 33.88)
35 | 0.35000000000000014 | (61.2, 10.8, 48.158) | (33.75, -13.35, 60.742) | (24.0, 1.95, 55.418) | (18.6, -5.4, 26.62) | (10.8, -15.6, 41.14) | (4.05, -7.5, 26.62) | (-2.4, -7.65, 44.044) | (9.15, -8.25, 28.072) | (2.25, -19.05, 34.122)
36 | 0.36000000000000015 | (57.9, 7.05, 51.062) | (35.1, -12.9, 63.162) | (23.7, 5.4, 55.66) | (16.2, -6.9, 26.862) | (10.05, -15.6, 41.866) | (4.35, -7.65, 26.136) | (-1.8, -6.15, 40.172) | (9.15, -8.4, 30.008) | (3.9, -18.6, 33.638)
37 | 0.37000000000000016 | (60.6, 10.5, 45.98) | (36.9, -12.3, 61.226) | (24.75, 5.7, 55.902) | (16.35, -5.55, 27.104) | (10.2, -15.75, 41.382) | (3.6, -6.6, 28.556) | (-1.5, -6.45, 41.624) | (9.45, -8.55, 30.008) | (2.7, -19.5, 35.574)
38 | 0.38000000000000017 | (57.9, 11.1, 48.4) | (35.55, -14.85, 63.162) | (23.55, 3.15, 53.966) | (17.25, -6.0, 24.926) | (11.4, -16.8, 43.076) | (4.5, -4.95, 26.862) | (-1.2, -7.2, 39.688) | (9.75, -9.0, 31.218) | (3.3, -17.1, 33.154)
39 | 0.3900000000000002 | (58.5, 9.0, 47.916) | (33.9, -14.55, 65.582) | (24.15, 4.2, 59.048) | (17.4, -5.85, 26.62) | (11.25, -14.7, 44.528) | (4.35, -7.2, 26.62) | (-2.4, -8.1, 40.172) | (10.95, -8.7, 28.798) | (3.3, -17.25, 35.332)
40 | 0.4000000000000002 | (55.8, 9.75, 47.916) | (37.2, -14.1, 60.984) | (22.2, 5.55, 55.176) | (16.35, -6.0, 27.346) | (11.85, -14.4, 43.076) | (3.9, -5.25, 29.04) | (-1.2, -8.4, 42.834) | (7.95, -7.35, 29.524) | (3.6, -18.45, 37.752)
41 | 0.4100000000000002 | (57.45, 11.1, 45.738) | (35.55, -13.5, 65.098) | (22.8, 4.5, 56.87) | (16.8, -5.55, 25.894) | (11.7, -15.0, 42.108) | (3.6, -4.95, 25.894) | (-2.85, -9.15, 41.624) | (9.0, -7.65, 31.702) | (4.05, -19.8, 34.848)
42 | 0.4200000000000002 | (55.2, 10.95, 46.222) | (33.75, -12.75, 69.454) | (22.95, 7.2, 53.966) | (18.0, -5.7, 25.652) | (12.75, -15.9, 41.866) | (2.85, -6.3, 27.346) | (-1.35, -9.3, 42.108) | (10.5, -7.5, 30.976) | (2.25, -18.75, 37.51)
43 | 0.4300000000000002 | (56.7, 10.2, 50.578) | (35.1, -16.5, 65.582) | (22.05, 6.3, 56.87) | (18.0, -5.1, 26.378) | (10.95, -16.2, 42.35) | (2.25, -5.55, 26.862) | (-1.05, -7.95, 42.35) | (8.25, -8.4, 29.524) | (3.45, -19.05, 34.364)
44 | 0.4400000000000002 | (58.95, 12.45, 46.706) | (34.05, -12.3, 62.678) | (21.6, 3.75, 53.724) | (16.35, -3.9, 29.04) | (10.65, -16.8, 40.656) | (2.85, -5.25, 26.378) | (-0.75, -9.0, 40.172) | (7.65, -7.8, 30.976) | (1.35, -18.9, 33.396)
45 | 0.45000000000000023 | (56.7, 8.55, 46.222) | (38.4, -13.65, 67.518) | (22.65, 2.55, 54.45) | (16.5, -7.05, 26.378) | (10.65, -15.0, 43.318) | (3.0, -6.45, 25.652) | (-1.2, -7.65, 41.866) | (7.5, -7.2, 27.104) | (3.45, -18.9, 34.122)
46 | 0.46000000000000024 | (56.4, 9.0, 46.464) | (38.1, -15.0, 62.678) | (22.8, 5.1, 54.692) | (15.6, -6.75, 27.346) | (11.25, -16.2, 42.35) | (2.25, -4.95, 28.556) | (-0.9, -7.5, 42.834) | (9.3, -7.8, 29.282) | (2.4, -18.15, 33.638)
47 | 0.47000000000000025 | (58.05, 10.35, 46.706) | (37.8, -15.3, 66.55) | (21.9, 1.35, 54.692) | (18.0, -6.0, 26.62) | (10.95, -16.2, 40.172) | (3.75, -5.85, 27.104) | (-1.8, -7.2, 40.656) | (10.35, -6.9, 31.702) | (3.0, -19.05, 34.122)
48 | 0.48000000000000026 | (57.6, 11.4, 49.126) | (35.4, -12.75, 64.614) | (24.3, 1.35, 55.176) | (17.7, -4.65, 27.346) | (11.4, -16.2, 40.898) | (3.6, -6.6, 26.62) | (-2.85, -7.65, 40.898) | (9.45, -8.55, 27.83) | (2.85, -19.2, 34.364)
49 | 0.49000000000000027 | (59.7, 11.55, 46.948) | (36.3, -14.25, 65.098) | (22.5, 4.65, 54.692) | (16.5, -6.3, 27.346) | (11.25, -15.3, 41.866) | (3.75, -5.7, 25.894) | (-2.1, -6.9, 40.898) | (9.9, -7.5, 28.556) | (3.75, -18.15, 37.268)
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

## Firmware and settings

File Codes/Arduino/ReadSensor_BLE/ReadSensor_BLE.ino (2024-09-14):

#include <bluefruit.h>
#include <Adafruit_LittleFS.h>
#include <InternalFileSystem.h>
#include "Adafruit_MLX90393.h"

// Total three MLX90393 sensors of the sensor array for the mini car
#define num 3

Adafruit_MLX90393 sensor[num];
// CS pins
int CS[num] = {2, 3, 4};

// BLE Service
BLEDfu  bledfu;  // OTA DFU service
BLEDis  bledis;  // device information
BLEUart bleuart; // uart over ble
BLEBas  blebas;  // battery

float data_array[num*3];   // The array to hold the data

void setup()
{
  dwt_enable();         // For more accurate micros() on Feather
  Serial.begin(115200);
#if CFG_DEBUG
  // Blocking wait for connection when debug mode is enabled via IDE
  while ( !Serial ) yield();
#endif
  //********************BLE SETUP*******************//
  Serial.println("Bluefruit52 BLEUART Example");
  Serial.println("---------------------------\n");

  // Setup the BLE LED to be enabled on CONNECT
  // Note: This is actually the default behavior, but provided
  // here in case you want to control this LED manually via PIN 19
  Bluefruit.autoConnLed(true);

  // Config the peripheral connection with maximum bandwidth 
  // more SRAM required by SoftDevice
  // Note: All config***() function must be called before begin()
  Bluefruit.configPrphBandwidth(BANDWIDTH_MAX);

  Bluefruit.begin();
  Bluefruit.setTxPower(4);    // Check bluefruit.h for supported values
  Bluefruit.setName("Bluefruit52");
  //Bluefruit.setName(getMcuUniqueID()); // useful testing with multiple central connections
  Bluefruit.Periph.setConnectCallback(connect_callback);
  Bluefruit.Periph.setDisconnectCallback(disconnect_callback);

  // To be consistent OTA DFU should be added first if it exists
  bledfu.begin();

  // Configure and Start Device Information Service
  bledis.setManufacturer("Adafruit Industries");
  bledis.setModel("Bluefruit Feather52");
  bledis.begin();

  // Configure and Start BLE Uart Service
  bleuart.begin();

  // Start BLE Battery Service
  blebas.begin();
  blebas.write(100);

  // Set up and start advertising
  startAdv();

  //*****************SENSOR SETUP*****************//
  pinMode(LED_BUILTIN, OUTPUT);     // Indicator of whether the sensors are all found
  digitalWrite(LED_BUILTIN, LOW);
  delayMicroseconds(2);
  for(int i = 0; i < num; ++i){
    sensor[i] = Adafruit_MLX90393();
    while (! sensor[i].begin_SPI(CS[i])) {
      Serial.print("No sensor ");
      Serial.print(i+1);
      Serial.println(" found ... check your wiring?");
      delayMicroseconds(500);
    } 
    Serial.print("Sensor ");
    Serial.print(i+1);
    Serial.println(" found!");
    // OSR: 3, Filter: 5, sapling rate: 17Hz
    while(!sensor[i].setOversampling(MLX90393_OSR_3)){
      Serial.print("Sensor ");
      Serial.print(i+1);
      Serial.println(" reset OSR!");
      delayMicroseconds(500);
    }
    delayMicroseconds(500);
    while(!sensor[i].setFilter(MLX90393_FILTER_5)){
      Serial.print("Sensor ");
      Serial.print(i+1);
      Serial.println(" reset filter!");
      delayMicroseconds(1000);
    }
  } 
  digitalWrite(LED_BUILTIN, HIGH);
  Serial.println("Found all MLX90393 sensors");
}

void startAdv(void)
{
  // Advertising packet
  Bluefruit.Advertising.addFlags(BLE_GAP_ADV_FLAGS_LE_ONLY_GENERAL_DISC_MODE);
  Bluefruit.Advertising.addTxPower();

  // Include bleuart 128-bit uuid
  Bluefruit.Advertising.addService(bleuart);

  // Secondary Scan Response packet (optional)
  // Since there is no room for 'Name' in Advertising packet
  Bluefruit.ScanResponse.addName();
  
  /* Start Advertising
   * - Enable auto advertising if disconnected
   * - Interval:  fast mode = 20 ms, slow mode = 152.5 ms
   * - Timeout for fast mode is 30 seconds
   * - Start(timeout) with timeout = 0 will advertise forever (until connected)
   * 
   * For recommended advertising interval
   * https://developer.apple.com/library/content/qa/qa1931/_index.html   
   */
  Bluefruit.Advertising.restartOnDisconnect(true);
  Bluefruit.Advertising.setInterval(32, 244);    // in unit of 0.625 ms
  Bluefruit.Advertising.setFastTimeout(30);      // number of seconds in fast mode
  Bluefruit.Advertising.start(0);                // 0 = Don't stop advertising after n seconds

}

void loop()
{ 
   Serial.println("###################");
   for(int i = 0; i < num; ++i){
      sensor[i].startSingleMeasurement();
      //delayMicroseconds(50);
   }
   delayMicroseconds(mlx90393_tconv[5][3]*1000+100); 
   for(int i = 0; i < num; ++i){
      if(!sensor[i].readMeasurement(&data_array[3*i], &data_array[3*i+1], &data_array[3*i+2])){
        Serial.print("Sensor ");
        Serial.print(i+1);
        Serial.println(" no data read!");
        digitalWrite(LED_BUILTIN, LOW);
      }
      delayMicroseconds(700);
//      Serial.print("Sensor ");
//      Serial.print(i+1);
//      Serial.print(data_array[3*i]);
//      Serial.print(" ");
//      Serial.print(data_array[3*i+1]);
//      Serial.print(" ");
//      Serial.print(data_array[3*i+2]);
    }

    // Send to PC using BLE
    bleuart.write((byte*)(data_array), num*3*4);
}

// callback invoked when central connects
void connect_callback(uint16_t conn_handle)
{
  // Get the reference to current connection
  BLEConnection* connection = Bluefruit.Connection(conn_handle);

  char central_name[32] = { 0 };
  connection->getPeerName(central_name, sizeof(central_name));

  Serial.print("Connected to ");
  Serial.println(central_name);
}

/**
 * Callback invoked when a connection is dropped
 * @param conn_handle connection where this event happens
 * @param reason is a BLE_HCI_STATUS_CODE which can be found in ble_hci.h
 */
void disconnect_callback(uint16_t conn_handle, uint8_t reason)
{
  (void) conn_handle;
  (void) reason;

  Serial.println();
  Serial.print("Disconnected, reason = 0x"); Serial.println(reason, HEX);
}

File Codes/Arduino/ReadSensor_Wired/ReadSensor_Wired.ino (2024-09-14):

#include "Adafruit_MLX90393.h"

// Total nine MLX90393 sensors for the sensor array
#define num 9
Adafruit_MLX90393 sensor[num];

// CS pins 
int CS[num] = {2, 3, 4, 5, 7, 9, 10, 11, 15};
//int CS[num] = {2, 3, 4};
float data_array[num*3];

void setup()
{
  // baud rate: 115200
  Serial.begin(115200);
  /* Wait for serial on USB platforms. */
  while (!Serial)
  {
    delayMicroseconds(10);
  }
  pinMode(LED_BUILTIN, OUTPUT);     // Indicator of whether the sensors are all found
  digitalWrite(LED_BUILTIN, LOW);
  delayMicroseconds(2);
  delayMicroseconds(1000);
  for (int i = 0; i < num; ++i)
  {
    sensor[i] = Adafruit_MLX90393();
    // Use SPI protocol
    while (!sensor[i].begin_SPI(CS[i]))
    {
      Serial.print("No sensor ");
      Serial.print(i + 1);
      Serial.println(" found ... check your wiring?");
      delayMicroseconds(500);
    }
    
    // OSR: 3, Filter: 3, sapling rate: 100Hz
    while (!sensor[i].setOversampling(MLX90393_OSR_3))
    {
      Serial.print("Sensor ");
      Serial.print(i + 1);
      Serial.println(" reset OSR!");
    }
    delayMicroseconds(500);
    while (!sensor[i].setFilter(MLX90393_FILTER_3))
    {
      Serial.print("Sensor ");
      Serial.print(i + 1);
      Serial.println(" reset filter!");
    }
    
  }
  digitalWrite(LED_BUILTIN, HIGH);
}


void loop()
{ 
  int start_time = micros();
  for(int i = 0; i < num; ++i)
  {
    sensor[i].startSingleMeasurement();
  }
  // time for converting data
  delayMicroseconds(mlx90393_tconv[3][3] * 1000+300);
  for(int i = 0; i < num; ++i)
  {
    sensor[i].readMeasurement(&data_array[3*i], &data_array[3*i+1], &data_array[3*i+2]);
  }
  // write bytes to PC
  Serial.write((byte*)(data_array), 4*(3*num)); 
}

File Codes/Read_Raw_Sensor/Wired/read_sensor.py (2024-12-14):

# We use this code to read the raw sensor data from the wired sensor.
# The sensor data will be saved in a csv file named "test_wired.csv".
# ctrl + c to stop the program

# import the necessary packages
# pip install pyserial
import serial
import struct

#  COM port, please change it to your own COM port
COM = 'COM3'
# number of sensors, please change it to the number of sensors you are using
num = 9
data = bytearray(4 * (3 * num))

arduino = serial.Serial(port=COM, baudrate=115200, timeout=None)

arduino.flushInput()
result = []
name = ['Time Stamp']
for i in range(num):
    name.append("Sensor " + str(i+1))

import datetime
import pandas as pd
# ctrl + c to stop the program
try:
    while True:
        arduino.flushInput()
        arduino.readinto(data)
        # print(data)
        current = [datetime.datetime.now()]
        for i in range(num):
            x, = struct.unpack('f', data[(i * 12):(4 + i * 12)])
            y, = struct.unpack('f', data[(i * 12 + 4):(8 + i * 12)])
            z, = struct.unpack('f', data[(i * 12 + 8):(12 + i * 12)])
            # 保留四位小数
            x = round(x, 4)
            y = round(y, 4)
            z = round(z, 4)
            current.append(
                "("+str(x) + ", " + str(y) + ", " + str(z)+")")
            print("Sensor " + str(i+1) + ": ", x, y, z)
        result.append(current)

# ctrl + c to stop the program 
except KeyboardInterrupt:
    print("Output csv")
    test = pd.DataFrame(columns=name, data=result)
    test.to_csv("test_wired.csv")
    print("Exited")

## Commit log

2024-08-05 update the arduino library
2024-08-05 upload the pcb files
    [MiniCar_SchDoc.SchDoc, RobotCar_SchDoc.SchDoc]
2024-08-08 upload pcb file
    [USB_Module_PcbDoc.PcbDoc, USB_Module_SchDoc.SchDoc]
2024-08-09 update the PCB files
2024-08-09 update the sensing pipeline
    [partitions.csv]
2024-09-13 update the polaris
    [RawData_1.csv, RawData_10.csv, RawData_11.csv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]
